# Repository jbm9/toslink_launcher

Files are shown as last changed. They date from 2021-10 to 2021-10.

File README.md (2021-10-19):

# TOSLink Launcher

Author: <josh@joshisanerd.com>

License: CC0 / Public Domain

This is a quick-and-dirty PCB mounted TOSLink launcher, which can
couple an SMD LED into a TOSLINK optical cable.  The project includes
both the FreeCAD model and a KiCad demo project (which you can pull
the library/module/STP file out of and into your own setup to use
these.)

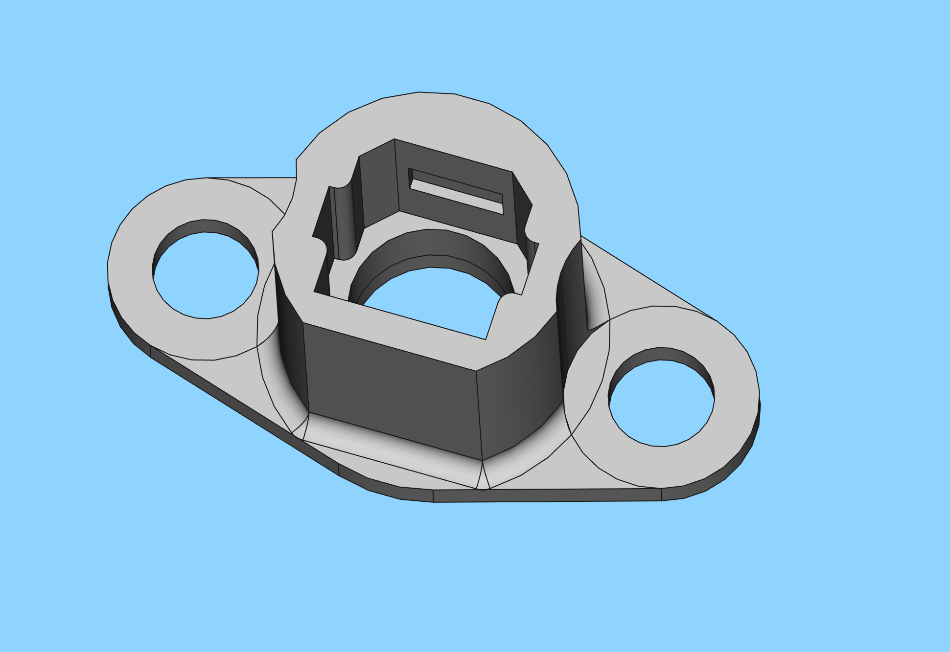
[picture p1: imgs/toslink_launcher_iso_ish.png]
Render of the connector


There is also an included STL file, but see below on the settings it
was printed with.

## Background
 
TOSLink is a really handy fiber optic cable: you can buy them easily,
reasonably cheaply, and in various lengths.  They are meant for audio,
but they're just flexible lightpipes at the end of the day.

You can buy TOSLink connectors that solder onto PCBs, but they only
come with red LEDs (which is used in the audio application).  If you
want to put arbitrary colors through them, it gets complicated.  So, I
decided to make a little connector that would let me mount a TOSLink
cable over an arbitrary surface mount LED.

## Limitations of included STL file

The STL included here assumes that your printer needs 0.2mm of
fudge-factor on each side to get good results on interior holes.  This
has been the case on both of my FDM printers, but it's probably going
to be suboptimal on SLA (or a particularly well-tuned FDM printer).

It is designed to put the end of the fiber cable 0.7mm above the
surface it's bolted down to.

## Mounting this on a PCB

The mounting arrangement for this is two holes 17mm apart.  I
recommend using 5mm drill hits for these, as you will need to align
the fiber optics perfectly with the LED underneath it.  To do this,
you want to move the connector around a little after it's mounted to
the PCB.  Putting M3 screws through a 5mm hole lets you move up to 1mm
in any direction from center, which should be good enough.

The recommended PCB footprint is an 8mm circle around those M5s, and a
13mm circle about your LED.  (I never claimed this was a
space-efficient footprint…)

## The KiCad demo project

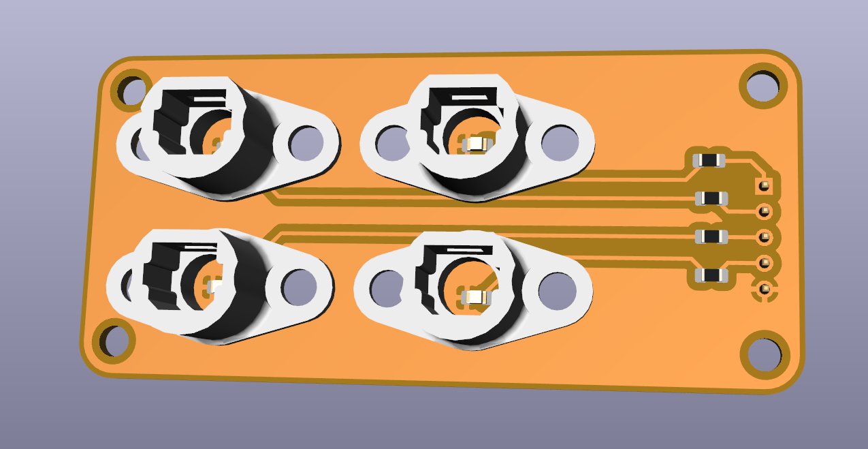
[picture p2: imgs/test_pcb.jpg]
KiCad's 3D view of the test PCB


There is a KiCad demo project in toslink_launcher_test.  Opening this
up in KiCad, then going to pcbnew, you should be able to do a 3D view
and see the parts rendered there.

The KiCad demo project includes a separate README.txt which describes
how to import all this into your own KiCad.

## The FreeCAD model

The model was developed in Ubuntu 20.04's distribution of FreeCAD, so
it's an ancient v0.18.4 file.  Apologies if it doesn't actually open
properly in newer versions.

This is a spreadsheet-driven FreeCAD file: if you need to adjust the
squeeze-out fudge factor, or the height of the LED, etc, you can open
the Spreadsheet in the file, tweak the values in that spreadsheet
(don't forget to include “mm” or FreeCAD will have a pedantic little
fit), and it should update the model.  You can then Activate the
“TOSLink Launcher001” Body object by double-clicking on it, and then
File > Export, and type in “toslink_launcher_foo.stl” (you also need
to add the STL there, FreeCAD's great).

This is also a reasonable starting point for the TOSLink connector;
there are precious few models using it, so hopefully this is a good
jumping-off point for anyone else who wants to use these cables for
alternate purposes.

## Further support

Please find someone to assist you with this: unfortunately, I don't
really have the time to help people with it.  This project is being
released more as a starting point for others than as a product in and
of itself.

## Contents:

* README.md: this file
* toslink_launcher.FCStd: FreeCAD v0.18.4 model
* toslink_launcher_v3.stl: STL of the actual launcher
* toslink_launcher_test/: KiCad demo project for the launcher
* imgs/: Images.

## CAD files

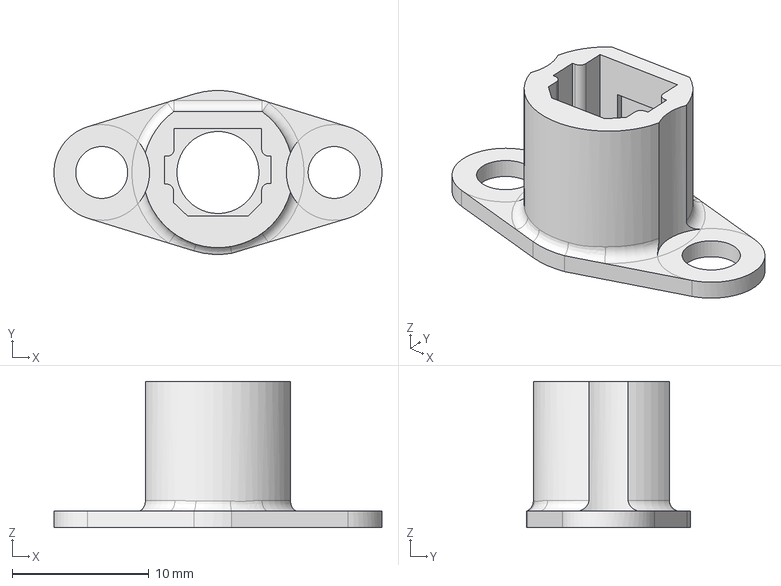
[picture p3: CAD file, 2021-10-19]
toslink_launcher_test/toslink_launcher.stp
24.0 x 12.0 x 10.7 mm

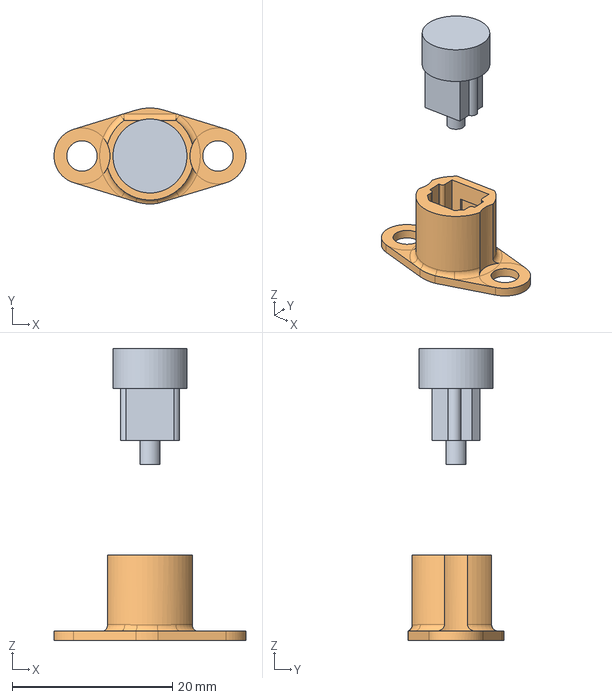
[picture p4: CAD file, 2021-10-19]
toslink_launcher.FCStd
24.0 x 12.0 x 36.5 mm
TOSLink Dummy
TOSLink Launcher001

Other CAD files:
toslink_launcher_v3.stl

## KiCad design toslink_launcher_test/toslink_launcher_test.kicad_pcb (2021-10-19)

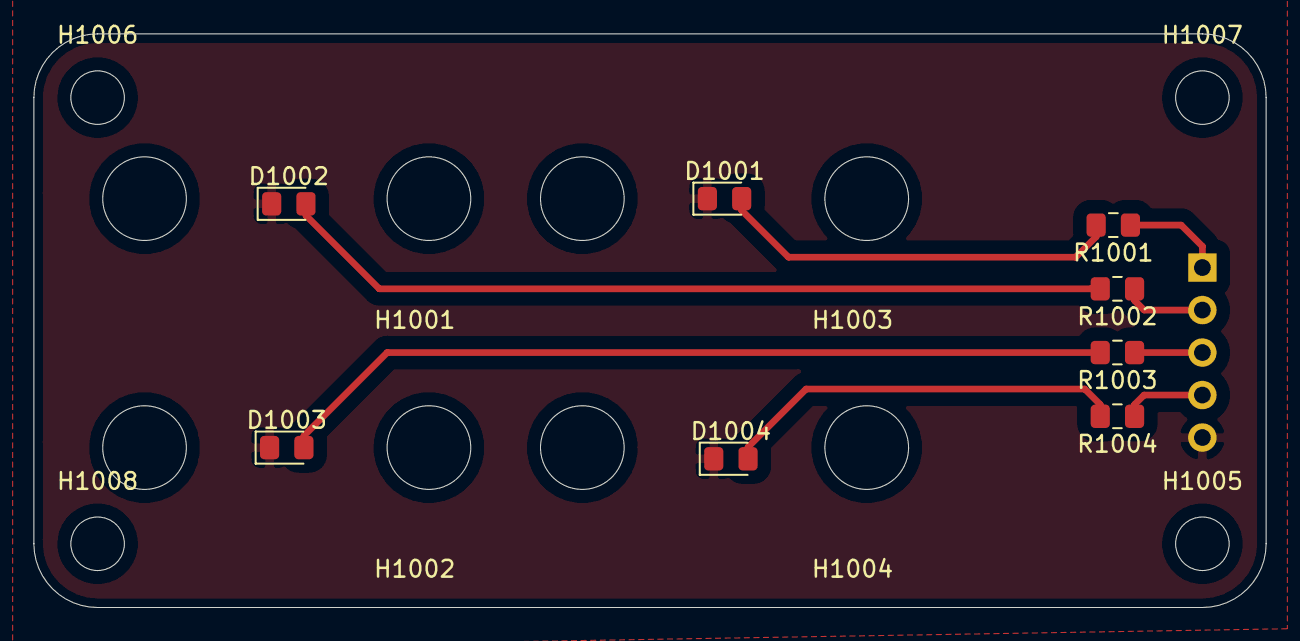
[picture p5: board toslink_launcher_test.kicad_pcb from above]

Board: 2 copper layers, 73.7 x 34.3 mm, 17 parts (1 on the bottom side), 9 nets.

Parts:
D1001, D1002, D1003, D1004: LED; LED_0805_2012Metric_Pad1.15x1.40mm_HandSolder
H1001, H1002, H1003, H1004: toslink_launcher
H1005, H1006, H1007, H1008: MountingHole; MountingHole_3.2mm_M3_ISO14580
J1001: Conn_01x05; PinHeader_1x05_P2.54mm_Vertical
R1001, R1002, R1003, R1004: R_Small; R_0805_2012Metric_Pad1.15x1.40mm_HandSolder

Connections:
GND: D1001.1, D1002.1, D1003.1, D1004.1, J1001.5
unnamed: D1001.2, R1001.2
unnamed: D1002.2, R1002.2
unnamed: D1003.2, R1003.2
unnamed: D1004.2, R1004.2
unnamed: J1001.1, R1001.1
unnamed: J1001.2, R1002.1
unnamed: J1001.3, R1003.1
unnamed: J1001.4, R1004.1

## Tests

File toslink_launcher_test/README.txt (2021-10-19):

# TOSLINK Launcher Example:$

Released: 2021-10-18

Author: Josh Myer <josh@joshisanerd.com}

This is a demo of the KiCad library/module/STP for the TOSLink Launcher.

## Smoke test

You should be able to open this project and use the 3D viewer on the PCB.
This demonstrates that you've got all the pieces together, and can use
them once you get them into your project in KiCad.

## Using the TOSLink Launcher in your project

To use this in your own project, just copy the library, module (the 
toslink_launcherjpretty directory), and the STP file into your project
directory.  You'll need to add them in your project, but hopefully you
won't need to reassociate the 3d model.  If you do, see below.

You need to do a few steps for this:
* Add the library (symbols) to  the project (in eeschema)
* Add the module (footprints) to the project (in pcbnew)
* Add the symbol for the launcher to your schematic
* Associate that symbol with the footprint in the association dialog

That should get it into your PCB.  It's just like adding mounting holes, but
with a custom library.

## Installing the TOSLink Launcher on finished PCBs

Once you have these on the PCB, you'll need 2 M3 screws and nuts for each
launcher you're using.  You should also use washers, but they are optional
for testing things out.  Screw the launcher down very gently, so that it can
still float around a bit.  Then, attach a TOSLINK fiber optic cable to your
 connector and turn the LED on.  You will then need to "float" the launcher
around until you get maximum brightness on the other side.  Then, very
carefully, tighten down the screws to lock it in place there.  Personally, I
usually need to leave the LED on so I can watch the intensity during this
particular process, as it's easy to move the cable ever-so-slightly off of the
optical axis, and dim the light a lot.

## Reassociating the 3D model for preview

If you do need to reassociate the 3d model with the footprint, go into the
footprint editor, edit the toslink_launcher footprint, and then go up to
Edit > Footprint Properties, then the 3D Settings tab and use the little
Folder icon to add the file with the second-least-helpful file chooser.
If it's any consolation, other parts of KiCad make you use the absolute
worst file chooser, so it could be worse?

Once you've done this, you'll need to update the foolprints in pcbnew.
To do that, go to Tools > Update footprints from library, then hit Apply.
This should re-load the footprints from the module, and get the new path
into the file.

## Further assistance

I can't help you with any of the above, but hopefully this is enough context
that you can find tutorials or a person that can help you in your language.

I hope this helps you make lots of neat stuff!

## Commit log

2021-10-19 Collecting the various project files into a single git repo and releasing it
    [toslink_launcher.FCStd, toslink_launcher.stp, toslink_launcher_test.kicad_pcb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]
2021-10-19 README.md: adds a preview image of the test PCB

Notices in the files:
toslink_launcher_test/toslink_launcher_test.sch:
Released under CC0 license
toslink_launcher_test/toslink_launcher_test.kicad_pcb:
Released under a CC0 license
